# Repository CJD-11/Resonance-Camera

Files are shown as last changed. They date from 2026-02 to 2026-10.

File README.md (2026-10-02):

# Resonance Camera

**Resonance Camera** is an experimental physical-computational imaging system that combines live camera imagery with measurements of environmental phenomena that are normally invisible.

The current system works across four complementary data layers:

* **USGS geomagnetic measurements** — ground-based magnetic-field vectors from the closest supported observatory
* **EPA RadNet** — geographically local or regional gamma-radiation measurements from the nearest configured monitor
* **NMDB** — regional neutron-monitor counts used as a proxy for secondary cosmic-ray activity at ground level
* **NOAA GOES** — proton and electron flux in the near-Earth space environment

The project does not attempt to show what radiation, magnetism, or particle activity literally “looks like.” Instead, it treats **measurement as material for visual translation**, combining scientific data with computational image-making.

---

## Current Data Model

```text
                     CAMERA LOCATION
                           │
          ┌────────────────┼────────────────┐
          │                │                │
          ▼                ▼                ▼
   USGS Geomag        EPA RadNet          NMDB
 ground magnetic      local/regional    regional cosmic-
     context            gamma data       ray neutron data
          │                │                │
          └──────────┬─────┴──────┬─────────┘
                     │            │
                     │            ▼
                     │        NOAA GOES
                     │       space-particle
                     │           flux
                     │            │
                     └──────┬─────┘
                            ▼
                      Raspberry Pi 4
                            │
                 normalization + caching
                            │
                      image mapping
                            │
                            ▼
                       visual output
```

Environmental measurements are retrieved independently from the live rendering loop and stored in a shared cache. The camera visualization reads only the latest in-memory snapshot, so network latency does not directly interrupt the live preview.

---

## Why the Project Moved Away From Onboard Sensors

Early prototypes used inexpensive onboard magnetometers and radiation sensors.

These components were valuable for testing the concept of direct environmental sensing, but their measurements were not stable or trustworthy enough to serve as the project’s primary data sources.

Magnetic readings were highly sensitive to:

* sensor orientation
* nearby electronics
* power wiring
* enclosure materials
* calibration

Radiation measurements introduced different limitations, including:

* long integration times
* low or inconsistent event counts
* sensor sensitivity
* difficulty validating readings against a calibrated reference

This led to a deliberate architectural shift:

> **Use established monitoring infrastructure for environmental measurement while keeping the interpretation and image-making process inside the camera.**

The original sensors remain useful for experimentation and comparison, but they are not treated as authoritative environmental measurements.

---

## Location-Responsive Data Selection

The software determines the camera location using:

1. explicit latitude / longitude configuration, or
2. approximate IP-based geolocation as a fallback

Explicit coordinates are recommended for field use.

The software then selects the most geographically relevant available sources:

* the nearest supported **USGS geomagnetic observatory**
* the nearest configured **EPA RadNet monitor**
* the nearest supported **NMDB neutron monitor**
* current **NOAA GOES** particle data

GOES differs from the other sources because it represents the broader near-Earth space environment rather than a measurement taken near the camera.

For a camera operating in Boston, the data hierarchy is approximately:

```text
Boston / camera location
        │
        ├── EPA RadNet Boston
        │      local environmental gamma context
        │
        ├── nearest compatible USGS observatory
        │      regional ground magnetic context
        │
        ├── NMDB Newark / Swarthmore
        │      regional secondary cosmic-ray context
        │
        └── NOAA GOES
               near-Earth proton / electron environment
```

A portrait made in Boston can therefore be influenced by environmental measurements relevant to that location without implying that a remote monitoring station directly measured radiation or particles striking the photographed individual.

---

## Visualization Modes

The environmental visualizations range from comparatively representational diagrams to intentionally abstract interpretations.

### Data-Informed / Schematic

**Field Lines**
Magnetic-vector direction and recent field variation control a dipole-like field projection.

**Particle Arrival**
GOES proton and electron activity controls incoming particle trajectories.

**Magnetosphere**
Combines geomagnetic measurements and space-particle activity into a schematic field-shell visualization.

**Local Radiation**
Nearby RadNet gamma measurements generate concentric interference structures around tracked bodies or the center of the frame.

**Cosmic Cascade**
NMDB neutron counts and GOES particle activity produce branching atmospheric shower-like traces.

### Abstract

**Signal Veil**
Layered membranes, discontinuities, and interruptions react to environmental activity.

**Resonance Map**
Topographic rings, gaps, spatial absences, and shifting contours respond to the incoming datasets.

**Data Bloom**
Environmental measurements radiate outward from tracked bodies or the center of the frame.

Earlier experimental visualization modes from the camera project are also retained in the repository.

---

## Color Treatments

Every visualization supports three global color modes.

### B&W + Color — Default

The photographic image is rendered in black and white while the environmental visualization remains in color.

### Full Color

Both the live camera image and visualization remain in color.

### Full B&W

The photographic image and visualization are both rendered monochromatically.

This allows the same visualization logic to move between documentary, graphic, and more abstract visual treatments without duplicating individual modes.

---

## Performance Strategy

Low-latency preview is a central design requirement.

The system separates tasks by update rate:

```text
Camera preview           up to ~30 fps target
Object detection         lower independent rate
USGS / GOES refresh      ~60 seconds
NMDB refresh             ~120 seconds
EPA RadNet refresh       ~5 minutes
```

Performance optimizations include:

* no API calls inside the frame-rendering loop
* cached environmental snapshots
* background network polling
* cached image-warp coordinate grids
* lightweight PIL / OpenCV overlays
* deterministic particle positioning instead of reallocating random effects every frame
* lower-resolution live preview
* higher-resolution saved captures

The result is a system where slow environmental measurements can influence a responsive live image without forcing the camera to operate at the speed of the APIs.

---

## Diagnostic Endpoint

The current environmental-data cache can be inspected at:

```text
http://<camera-address>:5000/environment_data
```

The JSON response includes:

* camera location
* selected USGS station and magnetic-field vector
* selected EPA RadNet monitor and gamma measurement
* selected NMDB monitor and neutron count rate
* NOAA GOES proton and electron flux
* source distance where applicable
* measurement timestamps
* API status and partial-data errors

This allows the data pipeline to be evaluated independently from the visual output.

---

## Hardware

| Component | Role | Approx. Cost |
| --- | --- | ---: |
| Raspberry Pi 4 | Primary computational platform | $55 |
| Arduino-compatible microcontroller | Hardware control / experimentation | $15 |
| ArduinoCam camera module | Image capture | $30 |
| Magnetometer | Experimental direct geomagnetic sensing | $10 |
| Radiation / particle sensor | Experimental direct radiation sensing | $60 |
| Environmental data services | Networked environmental measurements | $0 |
| Regulated power supply | System power | $20 |
| Custom 3D-printed enclosure + fabricated parts | Housing, mounting, internal structure, and assembly | $100 |
| Wiring, connectors & hardware | Internal assembly | $20 |
| **Estimated Prototype Total** | | **≈ $310 USD** |

The magnetometer and radiation sensor were used during early prototyping and remain useful for experimentation, but the current architecture relies primarily on established monitoring datasets.

---

## Camera Body + Fabrication

The camera body was developed as a multi-part CAD assembly measuring approximately **160 × 110 × 89 mm**.

The enclosure evolved through repeated cycles of:

```text
CAD → print → assemble → test → revise
```

Physical prototyping exposed constraints including:

* component clearance
* cable and wiring volume
* mating tolerances
* wall thickness
* print orientation
* fastener placement
* assembly order
* service access

The enclosure therefore developed alongside the electronics and software rather than as a decorative shell added after the technical system was complete.

---

## Interpretation + Limitations

Resonance Camera is an **artistic and experimental imaging instrument**, not a calibrated scientific, medical, radiation-safety, dosimetry, or navigation instrument.

EPA RadNet, NMDB, NOAA GOES, and USGS measurements are produced by different instruments operating at different geographic and temporal scales.

The project intentionally preserves these distinctions.

The final visual output should therefore be understood as a **data-informed interpretation of an environment**, not as a literal image of magnetic fields, radiation, cosmic rays, or particles surrounding a photographed subject.

---

## Data Sources

**U.S. EPA RadNet**
https://www.epa.gov/radnet/radnet-near-real-time-air-data

**USGS Geomagnetism Web Service**
https://www.usgs.gov/tools/web-service-geomagnetism-data

**NMDB Neutron Monitor Database**
https://www.nmdb.eu/

**NOAA Space Weather Prediction Center — GOES Data**
https://services.swpc.noaa.gov/json/goes/

NMDB data should be acknowledged according to NMDB and individual station-provider requirements. See `DATA_SOURCES.md` for implementation and attribution details.

---

## Author

**CJD-11**

https://github.com/CJD-11

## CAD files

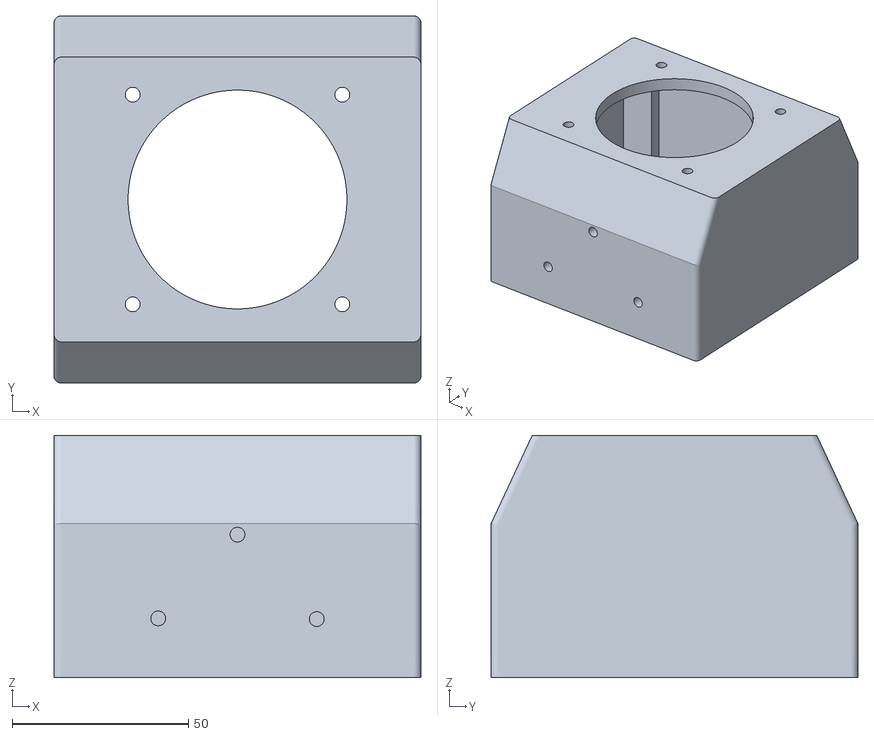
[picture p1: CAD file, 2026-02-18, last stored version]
digiObscura_Camera_Body_Final.stl
104.0 x 104.0 x 68.6

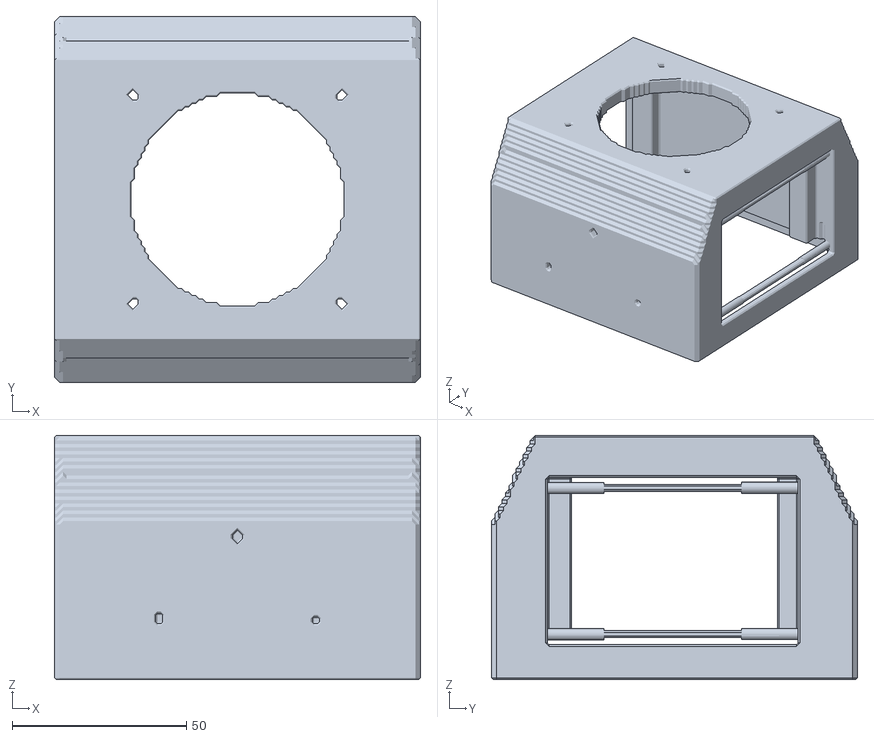
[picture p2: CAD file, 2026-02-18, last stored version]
camera_body_side_inserts_FIXED_uniform_rods_20mm.stl
105.0 x 105.0 x 70.0

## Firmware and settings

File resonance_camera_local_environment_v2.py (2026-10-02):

import io
import os
import math
import time
import threading
import random
import re
import colorsys
import json
import csv
import urllib.request
import urllib.parse
import cv2
import numpy as np
from datetime import datetime, timezone, timedelta
from flask import Flask, Response, render_template_string, jsonify, request
from picamera2 import Picamera2
from PIL import Image, ImageDraw, ImageFont, ImageEnhance, ImageOps, ImageFilter

SCRIPT_VERSION = "resonance-camera-2026.10-local-radnet-nmdb-goes-v2"

# ─── GPIO Setup ───────────────────────────────────────────────────────────────
try:
    from RPi import GPIO
    import subprocess

    BUTTON_PIN = int(os.environ.get("SHUTTER_PIN", "27"))  # Shutter button — GPIO27 / Pin 13
    # IMPORTANT: GPIO2/Pin 3 = I2C SDA and GPIO3/Pin 5 = I2C SCL.
    # The BMM150 magnetometer uses both lines.  GPIO3 may still be used as a
    # wake-from-halt button, but do not use it as the running script's normal
    # power/exit switch while I2C is active.  Default software power/run switch
    # is therefore GPIO17/Pin 11, wired to GND.
    POWER_PIN  = int(os.environ.get("POWER_PIN", "17"))      # Run/power switch — GPIO17 / Pin 11
    GEIGER_PIN = int(os.environ.get("GEIGER_PIN", "23"))     # Geiger pulse input — GPIO23 / Pin 16

    # Geiger modules should be read as a digital pulse input only.  This script
    # intentionally does not start PWM on GEIGER_PIN; a constant screech is
    # usually the module/buzzer, a stuck signal line, or the wrong pull/edge.
    GEIGER_PULL = os.environ.get("GEIGER_PULL", "UP").upper()       # UP, DOWN, OFF
    GEIGER_EDGE = os.environ.get("GEIGER_EDGE", "FALLING").upper()  # FALLING or RISING
    GEIGER_MIN_PULSE_GAP = float(os.environ.get("GEIGER_MIN_PULSE_GAP", "0.004"))
    GEIGER_DISABLE_EDGE = os.environ.get("GEIGER_DISABLE_EDGE", "0") == "1"

    # Switch behavior: "shutdown" safely powers down the Pi, while "exit"
    # stops only this Flask/Picamera script.  A GPIO switch cannot physically cut
    # 5V power by itself; use a latching power module/HAT for true power cut.
    POWER_ACTION = os.environ.get("POWER_ACTION", "shutdown").lower()  # shutdown or exit
    POWER_HOLD_SEC = float(os.environ.get("POWER_HOLD_SEC", "0.75"))
    DISABLE_POWER_SWITCH = os.environ.get("DISABLE_POWER_SWITCH", "0") == "1"
    ALLOW_POWER_ON_I2C = os.environ.get("ALLOW_POWER_ON_I2C", "0") == "1"
    I2C_GPIO_PINS = {2, 3}
    POWER_PIN_ENABLED = (not DISABLE_POWER_SWITCH) and (POWER_PIN not in I2C_GPIO_PINS or ALLOW_POWER_ON_I2C)

    GPIO.setwarnings(False)
    GPIO.setmode(GPIO.BCM)

    _PULL_MAP = {
        "UP": GPIO.PUD_UP,
        "DOWN": GPIO.PUD_DOWN,
        "OFF": GPIO.PUD_OFF,
        "NONE": GPIO.PUD_OFF,
    }
    _geiger_pull = _PULL_MAP.get(GEIGER_PULL, GPIO.PUD_UP)

    GPIO.setup(BUTTON_PIN, GPIO.IN, pull_up_down=GPIO.PUD_UP)
    if POWER_PIN_ENABLED:
        GPIO.setup(POWER_PIN, GPIO.IN, pull_up_down=GPIO.PUD_UP)
    elif POWER_PIN in I2C_GPIO_PINS:
        print(f"⚠ POWER_PIN=GPIO{POWER_PIN} is an I2C SDA/SCL pin used by the BMM150; script polling disabled for that pin.")
        print("  Use GPIO17/Pin 11 for the running power/run switch, or set ALLOW_POWER_ON_I2C=1 only if you are not using I2C.")
    else:
        print("ℹ Software power/run switch disabled by DISABLE_POWER_SWITCH=1.")
    GPIO.setup(GEIGER_PIN, GPIO.IN, pull_up_down=_geiger_pull)

    HAS_GPIO = True
    print(f"✓ GPIO ready. Geiger is INPUT-only on GPIO{GEIGER_PIN}; pull={GEIGER_PULL}, edge={GEIGER_EDGE}.")
except Exception as e:
    print(f"GPIO not available: {e}")
    HAS_GPIO = False

# ─── Magnetometer (BMM150 via I2C) ────────────────────────────────────────────
# Robust BMM150 support.  Prefer the Adafruit driver if installed, otherwise use
# a lightweight smbus2 reader with address scan and safer init timing.
HAS_MAG = False
_mag_driver = None
_mag_bus = None
_mag_sensor = None
BMM150_ADDR = None
MAG_STATUS = {
    "available": False,
    "driver": None,
    "addr": None,
    "error": None,
    "fail_count": 0,
}
_mag_last_heading = None
_mag_lock = threading.Lock()

def _sign_extend(value, bits):
    sign = 1 << (bits - 1)
    return (value & (sign - 1)) - (value & sign)

def _init_magnetometer():
    global HAS_MAG, _mag_driver, _mag_bus, _mag_sensor, BMM150_ADDR

    # Optional higher-level driver path.  If the library is not installed this
    # simply falls back to raw I2C below.
    try:
        import board
        import adafruit_bmm150
        _mag_sensor = adafruit_bmm150.BMM150_I2C(board.I2C())
        _mag_driver = "adafruit_bmm150"
        HAS_MAG = True
        MAG_STATUS.update({"available": True, "driver": _mag_driver, "addr": "auto", "error": None})
        print("✓ BMM150 magnetometer via adafruit_bmm150")
        return
    except Exception as e:
        MAG_STATUS["error"] = f"Adafruit driver unavailable: {e}"

    try:
        import smbus2
        _mag_bus = smbus2.SMBus(1)

        # Bosch's bare BMM150 address can be 0x10-0x13 depending on CSB/SDO;
        # many Raspberry Pi breakout boards default to 0x13.
        for addr in (0x10, 0x11, 0x12, 0x13):
            try:
                chip_id = _mag_bus.read_byte_data(addr, 0x40)
                if chip_id == 0x32:
                    BMM150_ADDR = addr
                    break
            except Exception:
                continue

        if BMM150_ADDR is None:
            raise RuntimeError("BMM150 chip id 0x32 not found at I2C addresses 0x10-0x13")

        # Power on, give the chip enough time to wake, then normal mode.
        _mag_bus.write_byte_data(BMM150_ADDR, 0x4B, 0x01)
        time.sleep(0.05)
        _mag_bus.write_byte_data(BMM150_ADDR, 0x4C, 0x00)  # normal mode
        _mag_bus.write_byte_data(BMM150_ADDR, 0x51, 0x04)  # XY repetitions
        _mag_bus.write_byte_data(BMM150_ADDR, 0x52, 0x0E)  # Z repetitions
        time.sleep(0.05)

        _mag_driver = "smbus2_raw"
        HAS_MAG = True
        MAG_STATUS.update({"available": True, "driver": _mag_driver, "addr": f"0x{BMM150_ADDR:02X}", "error": None})
        print(f"✓ BMM150 magnetometer at 0x{BMM150_ADDR:02X} via smbus2")
    except Exception as e:
        HAS_MAG = False
        MAG_STATUS.update({"available": False, "driver": None, "addr": None, "error": str(e)})
        print(f"Magnetometer not available: {e}")

_init_magnetometer()

def read_magnetometer():
    """Return compass heading in degrees, or None if the sensor is unavailable.

    Note: this is an un-tilt-compensated heading.  Keep the sensor roughly flat,
    and keep it away from the Pi/camera cable, magnets, and speaker/buzzer parts.
    """
    global _mag_last_heading
    if not HAS_MAG:
        return None

    try:
        with _mag_lock:
            if _mag_driver == "adafruit_bmm150" and _mag_sensor is not None:
                x, y, _z = _mag_sensor.magnetic
            else:
                # BMM150 raw data block:
                # X/Y are signed 13-bit values packed across LSB/MSB registers.
                data = _mag_bus.read_i2c_block_data(BMM150_ADDR, 0x42, 8)
                x = _sign_extend((data[1] << 5) | (data[0] >> 3), 13)
                y = _sign_extend((data[3] << 5) | (data[2] >> 3), 13)

            if x == 0 and y == 0:
                raise RuntimeError("zero magnetic vector")

            heading = (math.degrees(math.atan2(y, x)) + 360.0) % 360.0
            _mag_last_heading = round(heading, 1)
            MAG_STATUS["fail_count"] = 0
            MAG_STATUS["error"] = None
            return _mag_last_heading
    except Exception as e:
        MAG_STATUS["fail_count"] += 1
        MAG_STATUS["error"] = str(e)
        return None

def magnetometer_poll_loop():
    """Keep a low-rate cached heading so the video renderer never waits on I2C."""
    while True:
        read_magnetometer()
        time.sleep(0.20)

threading.Thread(target=magnetometer_poll_loop, daemon=True, name='magnetometer-poll').start()

# ─── Geiger Counter ───────────────────────────────────────────────────────────
# Rolling 60-second timestamp window for CPM.  GPIO23 is read as an input only;
# no PWM is created here.  If the board screeches continuously when powered,
# check whether the onboard buzzer/alarm is enabled and confirm OUT/INT is wired
# to GPIO23, not the buzzer or HV/power pin.
import collections as _collections
CPM_WINDOW        = 60       # seconds
PULSE_HISTORY_LEN = 1000     # max timestamps to keep
CPM_TO_USVH       = 1.0 / 153.8  # Cajoe RadiationD-v1.1 / J305 tube conversion
GEIGER_STUCK_CPS  = float(os.environ.get("GEIGER_STUCK_CPS", "25"))  # noisy/stuck-line warning

_pulse_times = _collections.deque(maxlen=PULSE_HISTORY_LEN)
_geiger_lock = threading.Lock()
_geiger_last_pulse = 0.0
_geiger_rejected = 0
_geiger_edge_active = False
geiger_data  = {
    'cpm': 0.0,
    'usvh': 0.0,
    'pulses': 0,
    'rejected': 0,
    'status': 'offline' if not HAS_GPIO else 'waiting',
    'line': None,
}

def geiger_pulse(channel=None):
    """Register one Geiger pulse, ignoring impossible chatter/glitches."""
    global _geiger_last_pulse, _geiger_rejected
    now = time.monotonic()
    with _geiger_lock:
        gap = now - _geiger_last_pulse if _geiger_last_pulse else 999.0
        if gap < GEIGER_MIN_PULSE_GAP:
            _geiger_rejected += 1
            geiger_data['rejected'] = _geiger_rejected
            return
        _geiger_last_pulse = now
        _pulse_times.append(now)
        geiger_data['pulses'] += 1
        geiger_data['status'] = 'pulse'

def _geiger_edge_constant():
    if not HAS_GPIO:
        return None
    return GPIO.RISING if GEIGER_EDGE == "RISING" else GPIO.FALLING

if HAS_GPIO:
    try:
        GPIO.remove_event_detect(GEIGER_PIN)  # clear any stale state from previous run
    except Exception:
        pass

    if not GEIGER_DISABLE_EDGE:
        try:
            GPIO.add_event_detect(
                GEIGER_PIN,
                _geiger_edge_constant(),
                callback=geiger_pulse,
                bouncetime=max(1, int(GEIGER_MIN_PULSE_GAP * 1000)),
            )
            _geiger_edge_active = True
            geiger_data['status'] = 'edge'
            print(f"✓ Geiger edge detection active on GPIO{GEIGER_PIN} ({GEIGER_EDGE}, input-only; no PWM)")
        except RuntimeError as e:
            geiger_data['status'] = 'poll'
            print(f"Geiger edge detect failed ({e}) — using poll fallback")
    else:
        geiger_data['status'] = 'poll'
        print("Geiger edge detection disabled by GEIGER_DISABLE_EDGE=1 — using poll fallback")

def geiger_poll_loop():
    """Fallback sampler for Geiger modules/OS builds where edge detection fails."""
    if not HAS_GPIO or _geiger_edge_active:
        return
    try:
        last = GPIO.input(GEIGER_PIN)
    except Exception:
        return

    while True:
        try:
            state = GPIO.input(GEIGER_PIN)
            falling = (last == GPIO.HIGH and state == GPIO.LOW)
            rising  = (last == GPIO.LOW  and state == GPIO.HIGH)
            if (GEIGER_EDGE == "RISING" and rising) or (GEIGER_EDGE != "RISING" and falling):
                geiger_pulse(GEIGER_PIN)
            last = state
        except Exception:
            pass
        time.sleep(0.001)

def geiger_cpm_loop():
    """Update CPM every second using a rolling 60-second window."""
    while True:
        time.sleep(1)
        now    = time.monotonic()
        cutoff = now - CPM_WINDOW
        short_cutoff = now - 5.0
        with _geiger_lock:
            recent  = [t for t in _pulse_times if t >= cutoff]
            recent5 = [t for t in _pulse_times if t >= short_cutoff]
            elapsed = min(now - _pulse_times[0], CPM_WINDOW) if _pulse_times else CPM_WINDOW
            rejected = _geiger_rejected
        if elapsed < 1:
            elapsed = 1

        cpm  = round(len(recent) / elapsed * 60.0, 1)
        usvh = round(cpm * CPM_TO_USVH, 4)
        cps5 = len(recent5) / 5.0

        line_state = None
        if HAS_GPIO:
            try:
                line_state = GPIO.input(GEIGER_PIN)
            except Exception:
                line_state = None

        status = 'ok'
        if not HAS_GPIO:
            status = 'offline'
        elif cps5 >= GEIGER_STUCK_CPS:
            status = 'noisy/stuck'
        elif len(recent) == 0:
            status = 'waiting'
        elif rejected > 0:
            status = 'filtered'

        with _geiger_lock:
            geiger_data['cpm']      = cpm
            geiger_data['usvh']     = usvh
            geiger_data['line']     = line_state
            geiger_data['rejected'] = rejected
            geiger_data['status']   = status

threading.Thread(target=geiger_poll_loop, daemon=True).start()
threading.Thread(target=geiger_cpm_loop, daemon=True).start()

# ─── Networked Environmental Data ─────────────────────────────────────────────
# Network I/O stays off the render thread. A background worker refreshes four
# complementary layers and stores only compact cached snapshots:
#   1) USGS ground geomagnetism
#   2) EPA RadNet local/regional environmental gamma radiation
#   3) NMDB neutron-monitor cosmic-ray counts
#   4) NOAA GOES proton/electron flux in near-Earth space
# The live renderer only reads this cache, so a slow API cannot stall the camera.
ENV_REFRESH_SEC = float(os.environ.get("ENV_REFRESH_SEC", "60"))
RADNET_REFRESH_SEC = float(os.environ.get("RADNET_REFRESH_SEC", "300"))
NMDB_REFRESH_SEC = float(os.environ.get("NMDB_REFRESH_SEC", "120"))
ENV_HTTP_TIMEOUT = float(os.environ.get("ENV_HTTP_TIMEOUT", "5.0"))
AUTO_IP_LOCATION = os.environ.get("AUTO_IP_LOCATION", "1") == "1"
CAMERA_LAT = os.environ.get("CAMERA_LAT")
CAMERA_LON = os.environ.get("CAMERA_LON")
CAMERA_LOCATION_NAME = os.environ.get("CAMERA_LOCATION_NAME", "")
CAMERA_CITY = os.environ.get("CAMERA_CITY", "")
CAMERA_STATE = os.environ.get("CAMERA_STATE", "").upper()
GEOMAG_STATION_OVERRIDE = os.environ.get("GEOMAG_STATION", "").strip().upper()
RADNET_CITY_OVERRIDE = os.environ.get("RADNET_CITY", "").strip()
RADNET_STATE_OVERRIDE = os.environ.get("RADNET_STATE", "").strip().upper()
NMDB_STATION_OVERRIDE = os.environ.get("NMDB_STATION", "").strip().upper()
LOCATION_REFRESH_SEC = float(os.environ.get("LOCATION_REFRESH_SEC", "1800"))

# USGS observatory coordinates. Used only to choose a compatible station; actual
# values come from the USGS Geomagnetism Web Service.
USGS_GEOMAG_STATIONS = {
    'BOU': {'name': 'Boulder, CO', 'lat': 40.1375, 'lon': -105.2372},
    'BRW': {'name': 'Barrow, AK', 'lat': 71.3226, 'lon': -156.6231},
    'BSL': {'name': 'Stennis Space Center, MS', 'lat': 30.3504, 'lon': -89.6351},
    'CMO': {'name': 'College, AK', 'lat': 64.8742, 'lon': -147.8597},
    'DED': {'name': 'Deadhorse, AK', 'lat': 70.3552, 'lon': -148.7928},
    'FRD': {'name': 'Fredericksburg, VA', 'lat': 38.2047, 'lon': -77.3729},
    'FRN': {'name': 'Fresno, CA', 'lat': 37.0913, 'lon': -119.7193},
    'GUA': {'name': 'Guam', 'lat': 13.5894, 'lon': 144.8694},
    'HON': {'name': 'Honolulu, HI', 'lat': 21.3166, 'lon': -158.0001},
    'NEW': {'name': 'Newport, WA', 'lat': 48.2649, 'lon': -117.1231},
    'SHU': {'name': 'Shumagin, AK', 'lat': 55.3472, 'lon': -160.4645},
    'SIT': {'name': 'Sitka, AK', 'lat': 57.0576, 'lon': -135.3273},
    'SJG': {'name': 'San Juan, PR', 'lat': 18.1110, 'lon': -66.1500},
    'TUC': {'name': 'Tucson, AZ', 'lat': 32.1742, 'lon': -110.7337},
}

# RadNet monitors are identified by city/state in the public CSV service. EPA
# notes historical station coordinates are often city-centroid based. This
# registry prioritizes the Northeast / current Boston test region and several
# common US locations; exact city matches always win, and overrides are exposed
# for any station not listed here.
RADNET_STATIONS = [
    {'city':'Boston','state':'MA','lat':42.3601,'lon':-71.0589},
    {'city':'Worcester','state':'MA','lat':42.2626,'lon':-71.8023},
    {'city':'Providence','state':'RI','lat':41.8240,'lon':-71.4128},
    {'city':'Portsmouth','state':'NH','lat':43.0718,'lon':-70.7626},
    {'city':'Concord','state':'NH','lat':43.2081,'lon':-71.5376},
    {'city':'Portland','state':'ME','lat':43.6591,'lon':-70.2568},
    {'city':'Orono','state':'ME','lat':44.8831,'lon':-68.6719},
    {'city':'Burlington','state':'VT','lat':44.4759,'lon':-73.2121},
    {'city':'Albany','state':'NY','lat':42.6526,'lon':-73.7562},
    {'city':'New York City','state':'NY','lat':40.7128,'lon':-74.0060},
    {'city':'Yaphank','state':'NY','lat':40.8368,'lon':-72.9170},
    {'city':'Edison','state':'NJ','lat':40.5187,'lon':-74.4121},
    {'city':'Philadelphia','state':'PA','lat':39.9526,'lon':-75.1652},
    {'city':'Baltimore','state':'MD','lat':39.2904,'lon':-76.6122},
    {'city':'Washington','state':'DC','lat':38.9072,'lon':-77.0369},
    {'city':'Richmond','state':'VA','lat':37.5407,'lon':-77.4360},
    {'city':'Virginia Beach','state':'VA','lat':36.8529,'lon':-75.9780},
    {'city':'Charlotte','state':'NC','lat':35.2271,'lon':-80.8431},
    {'city':'Raleigh','state':'NC','lat':35.7796,'lon':-78.6382},
    {'city':'Atlanta','state':'GA','lat':33.7490,'lon':-84.3880},
    {'city':'Miami','state':'FL','lat':25.7617,'lon':-80.1918},
    {'city':'Chicago','state':'IL','lat':41.8781,'lon':-87.6298},
    {'city':'Detroit','state':'MI','lat':42.3314,'lon':-83.0458},
    {'city':'St. Louis','state':'MO','lat':38.6270,'lon':-90.1994},
    {'city':'Dallas','state':'TX','lat':32.7767,'lon':-96.7970},
    {'city':'Austin','state':'TX','lat':30.2672,'lon':-97.7431},
    {'city':'Denver','state':'CO','lat':39.7392,'lon':-104.9903},
    {'city':'Albuquerque','state':'NM','lat':35.0844,'lon':-106.6504},
    {'city':'Las Vegas','state':'NV','lat':36.1699,'lon':-115.1398},
    {'city':'Reno','state':'NV','lat':39.5296,'lon':-119.8138},
    {'city':'Seattle','state':'WA','lat':47.6062,'lon':-122.3321},
    {'city':'Portland','state':'OR','lat':45.5152,'lon':-122.6784},
    {'city':'Honolulu','state':'HI','lat':21.3099,'lon':-157.8581},
    {'city':'Anchorage','state':'AK','lat':61.2181,'lon':-149.9003},
]

# A compact North-American NMDB registry is enough to make the cosmic-ray layer
# geographically meaningful without querying every world station each cycle.
# Newark/Swarthmore (NEWK) is normally the closest NMDB monitor to Boston.
NMDB_STATIONS = {
    'NEWK': {'name':'Newark/Swarthmore, USA', 'lat':39.68, 'lon':-75.75},
    'CALG': {'name':'Calgary, Canada', 'lat':51.08, 'lon':-114.13},
    'FSMT': {'name':'Fort Smith, Canada', 'lat':60.02, 'lon':-111.93},
    'INVK': {'name':'Inuvik, Canada', 'lat':68.36, 'lon':-133.72},
    'NAIN': {'name':'Nain, Canada', 'lat':56.55, 'lon':-61.68},
    'MXCO': {'name':'Mexico City, Mexico', 'lat':19.33, 'lon':-99.18},
}

_env_lock = threading.Lock()
environment_data = {
    'status': 'starting', 'updated': None, 'error': None,
    'location': {'lat': None, 'lon': None, 'name': None, 'city':None, 'state':None, 'source': None},
    'geomag': {
        'available': False, 'station': None, 'station_name': None, 'distance_km': None,
        'time': None, 'x': None, 'y': None, 'z': None, 'f': None,
        'horizontal': None, 'declination_deg': None, 'inclination_deg': None,
        'variation_nt': 0.0, 'activity': 0.0, 'source': 'USGS Geomagnetism',
    },
    'radiation': {
        'available': False, 'station': None, 'distance_km': None, 'time': None,
        'gamma_mean': None, 'exposure_rate': None, 'activity': 0.0,
        'source': 'EPA RadNet', 'note': 'local/regional station measurement',
    },
    'cosmic': {
        'available': False, 'station': None, 'station_name': None, 'distance_km': None,
        'time': None, 'count_rate': None, 'relative_percent': None, 'activity': 0.0,
        'source': 'NMDB', 'note': 'regional secondary cosmic-ray neutron monitor',
    },
    'particles': {
        'available': False, 'time': None, 'satellite': None,
        'proton_10': 0.0, 'proton_50': 0.0, 'proton_100': 0.0,
        'electron': 0.0, 'activity': 0.0, 'source': 'NOAA SWPC GOES',
        'note': 'near-Earth space environment; not local to the camera',
    },
}
_location_cache = {'ts': 0.0, 'value': None}
_source_cache = {'radnet_ts':0.0, 'radnet':None, 'nmdb_ts':0.0, 'nmdb':None}


def _http_bytes(url, timeout=ENV_HTTP_TIMEOUT, accept='*/*'):
    req = urllib.request.Request(url, headers={
        'User-Agent': 'ResonanceCamera/2.0 (+https://github.com/CJD-11/Resonance-Camera)',
        'Accept': accept,
    })
    with urllib.request.urlopen(req, timeout=timeout) as r:
        return r.read()


def _http_json(url, timeout=ENV_HTTP_TIMEOUT):
    return json.loads(_http_bytes(url, timeout, 'application/json').decode('utf-8', errors='replace'))


def _http_text(url, timeout=ENV_HTTP_TIMEOUT):
    return _http_bytes(url, timeout, 'text/plain,text/csv,*/*').decode('utf-8-sig', errors='replace')


def _haversine_km(lat1, lon1, lat2, lon2):
    p1, p2 = math.radians(lat1), math.radians(lat2)
    dp = math.radians(lat2-lat1); dl = math.radians(lon2-lon1)
    a = math.sin(dp/2)**2 + math.cos(p1)*math.cos(p2)*math.sin(dl/2)**2
    return 6371.0088 * 2 * math.asin(min(1.0, math.sqrt(a)))
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

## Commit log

2026-11-05 Create 3D Printed Materials
2026-11-05 Create STL
